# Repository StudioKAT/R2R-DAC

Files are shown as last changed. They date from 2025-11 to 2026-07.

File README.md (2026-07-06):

# R2R DAC
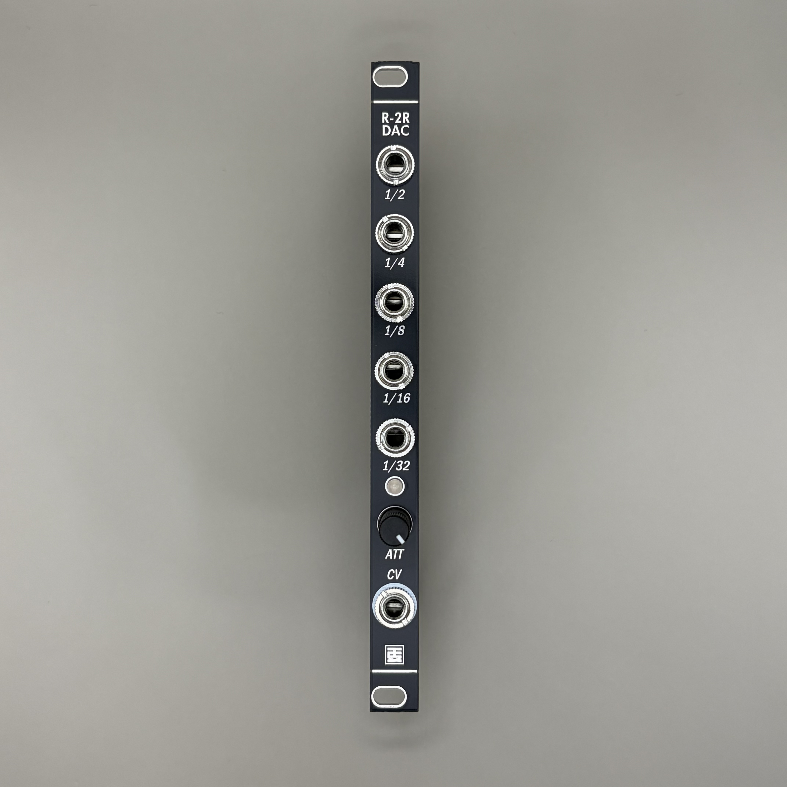
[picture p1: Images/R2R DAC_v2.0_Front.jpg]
R2R DAC_v2.0_Front


## 概要 / Overview

**R2R DAC** は、5つのゲート信号を階段状のコントロール電圧（CV）に変換する、2HPサイズのR-2RラダーDACモジュールです。
5つのゲート入力（/2, /4, /8, /16, /32）のON/OFFの組み合わせによって、0〜31段階のステップ電圧を生成する5ビットのデジタル→アナログ変換器として動作します。

クロックディバイダーやゲートシーケンサーと組み合わせることで、周期的な階段波、疑似ランダムなCVパターン、アルペジオ風のピッチ変化、フィルターやVCAのステップモジュレーションなどを簡単に作ることができます。
CV出力にはアッテネーターを備えており、ピッチCVからモジュレーション用途まで、パッチに合わせて出力レベルを調整できます。

**Update:** v2.0では、v1.0の4ビット仕様から5ビット仕様へ変更され、生成できるステップ数が16段階から32段階に拡張されました。

**R2R DAC** is a compact 2HP R-2R ladder DAC module that converts five gate signals into stepped control voltages (CV).
By combining the ON/OFF states of the five gate inputs (/2, /4, /8, /16, /32), it functions as a 5-bit digital-to-analog converter capable of generating 32 discrete voltage steps (0–31).

When paired with clock dividers or gate sequencers, it can create stepped waveforms, pseudo-random CV patterns, arpeggio-like pitch movement, or stepped modulation for filters, VCAs, and other CV destinations.
The CV output is equipped with an attenuator, allowing the output level to be adjusted for anything from pitch control to general modulation use.

**Update:** In v2.0, the design has been updated from the 4-bit configuration of v1.0 to a 5-bit R-2R DAC, expanding the available resolution from 16 steps to 32 steps.

## 仕様 / Spec
- Format: Eurorack
- Function: R2R DAC
- Current needs: +12V: 15mA, -12V: 15mA
- Width: 2 HP
- Depth: 28mm (including power connector)

## 販売 / Sales

StudioKATオフィシャルショップで販売しています。(日本国内限定)  
https://www.studiokat.jp/items/149564763

## ライセンス / License

この作品は [Creative Commons 表示 - 継承 4.0 国際 (CC BY-SA 4.0)](https://creativecommons.org/licenses/by-sa/4.0/deed.ja) の下でライセンスされています。  
This work is licensed under the [Creative Commons Attribution-ShareAlike 4.0 International License](https://creativecommons.org/licenses/by-sa/4.0/).

## クレジット / Credits

- Designed by : StudioKAT
- Website : https://www.studiokat.jp/
- GitHub : https://github.com/StudioKAT
- X(Twitter) : https://x.com/StudioKAT_synth
- Instagram : https://www.instagram.com/studiokat_modular/

## 更新履歴 / Changelog

- `2025-11-22` v1.0 Released version 1.0
- `2026-07-05` v2.0 Released version 2.0

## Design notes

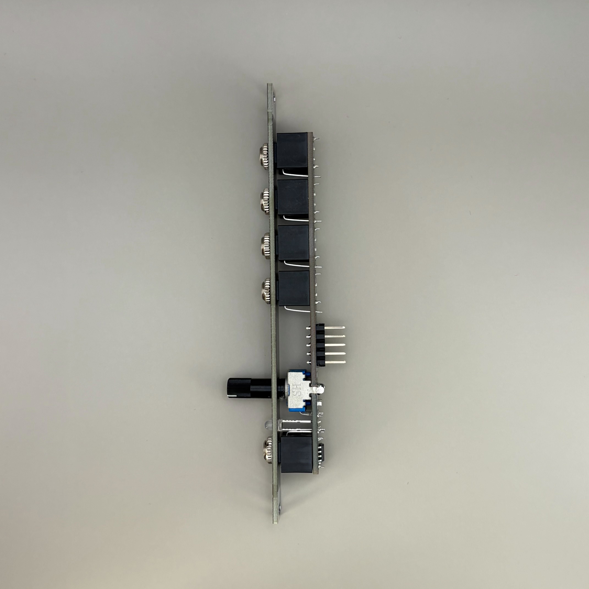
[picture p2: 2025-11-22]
Images/R2R DAC_v1.0_Side.jpg

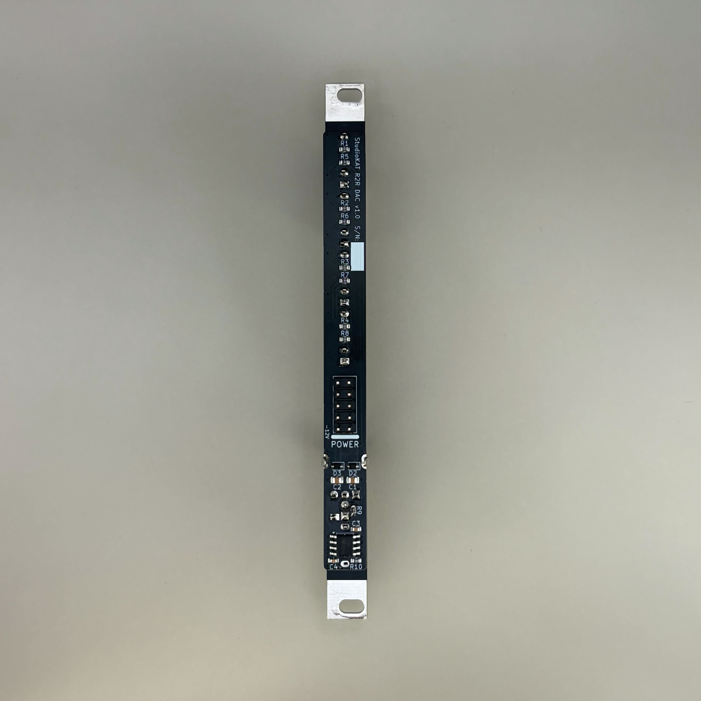
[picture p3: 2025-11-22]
Images/R2R DAC_v1.0_Back.jpg

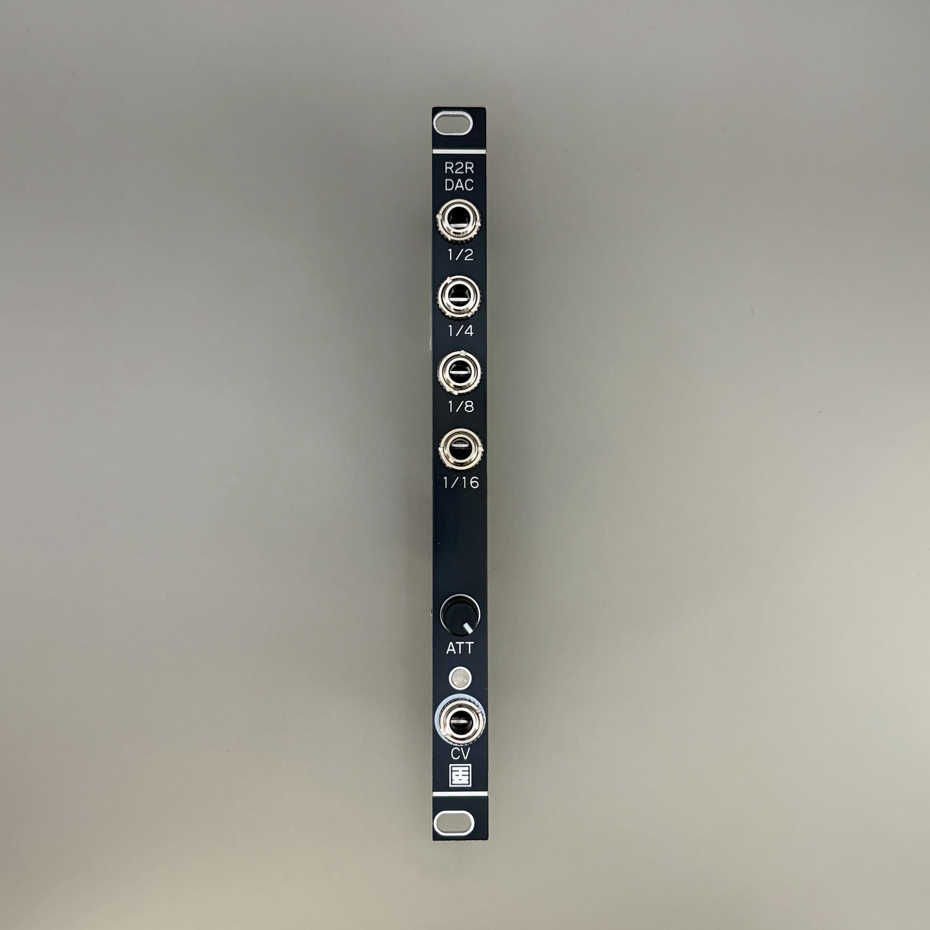
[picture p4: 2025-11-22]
Images/R2R DAC_v1.0_Front.jpg

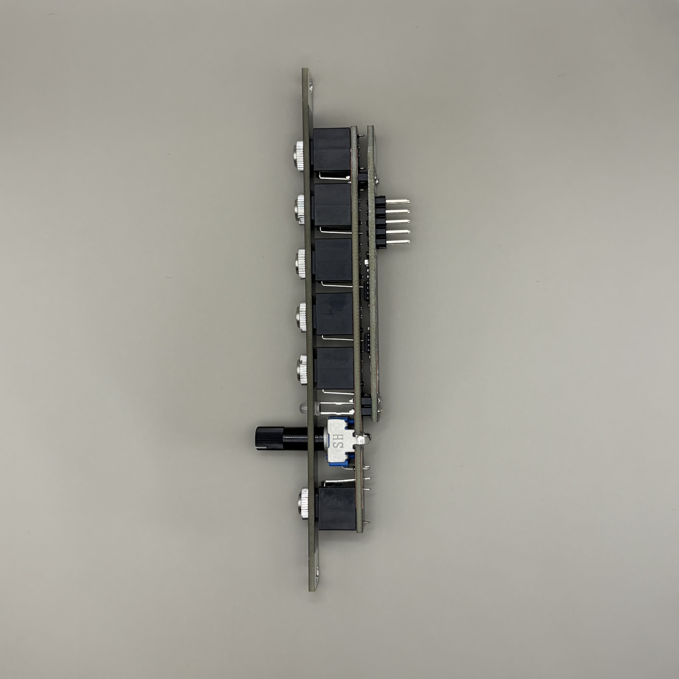
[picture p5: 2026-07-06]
Images/R2R DAC_v2.0_Side.jpg

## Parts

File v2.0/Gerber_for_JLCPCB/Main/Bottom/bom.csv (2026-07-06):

Designator | Footprint | Quantity | Value | LCSC Part #
C1, C2 | 0805 | 2 | 22uF | C45783
C3, C4, C5, C6, C7, C8 | 0603 | 6 | 100nF | C14663
D1, D2 | D_SOD-323 | 2 | 1N5819WS | C64886
J1 | PinHeader_2x05_2.54mm_Europower | 1 | POWER
J12, J13 | PinSocket_1x01_P2.54mm_Vertical | 2 | Conn_01x01_Socket
J14, J15 | PinSocket_1x02_P2.54mm_Vertical | 2 | Conn_01x02_Socket
R11, R12 | 0603 | 2 | 100K | C25803
R13 | 0603 | 1 | 1K | C21190
R14 | 0603 | 1 | 4.7K | C23162
U1, U2 | SOIC-8_3.9x4.9mm_P1.27mm | 2 | TL072CDT | C6961

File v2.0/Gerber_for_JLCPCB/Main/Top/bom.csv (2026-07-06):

Designator | Footprint | Quantity | Value | LCSC Part #
D3 | LED_D3.0mm_Clear | 1 | LED_Dual_Bidirectional
J10, J11 | PinHeader_1x02_P2.54mm_Vertical | 2 | Conn_01x02_Pin
J2 | AudioJack_PJ301M-12 | 1 | IN_1/2
J3 | AudioJack_PJ301M-12 | 1 | IN_1/4
J4 | AudioJack_PJ301M-12 | 1 | IN_1/8
J5 | AudioJack_PJ301M-12 | 1 | IN_1/16
J6 | AudioJack_PJ301M-12 | 1 | IN_1/32
J7 | AudioJack_PJ301M-12 | 1 | CV OUT
J8, J9 | PinHeader_1x01_P2.54mm_Vertical | 2 | Conn_01x01_Pin
R1, R10, R2, R3, R4, R5 | 0603 | 6 | 30K | C22984
R6, R7, R8, R9 | 0603 | 4 | 15K | C22809
RV1 | Potentiometer_RV09 | 1 | B100K

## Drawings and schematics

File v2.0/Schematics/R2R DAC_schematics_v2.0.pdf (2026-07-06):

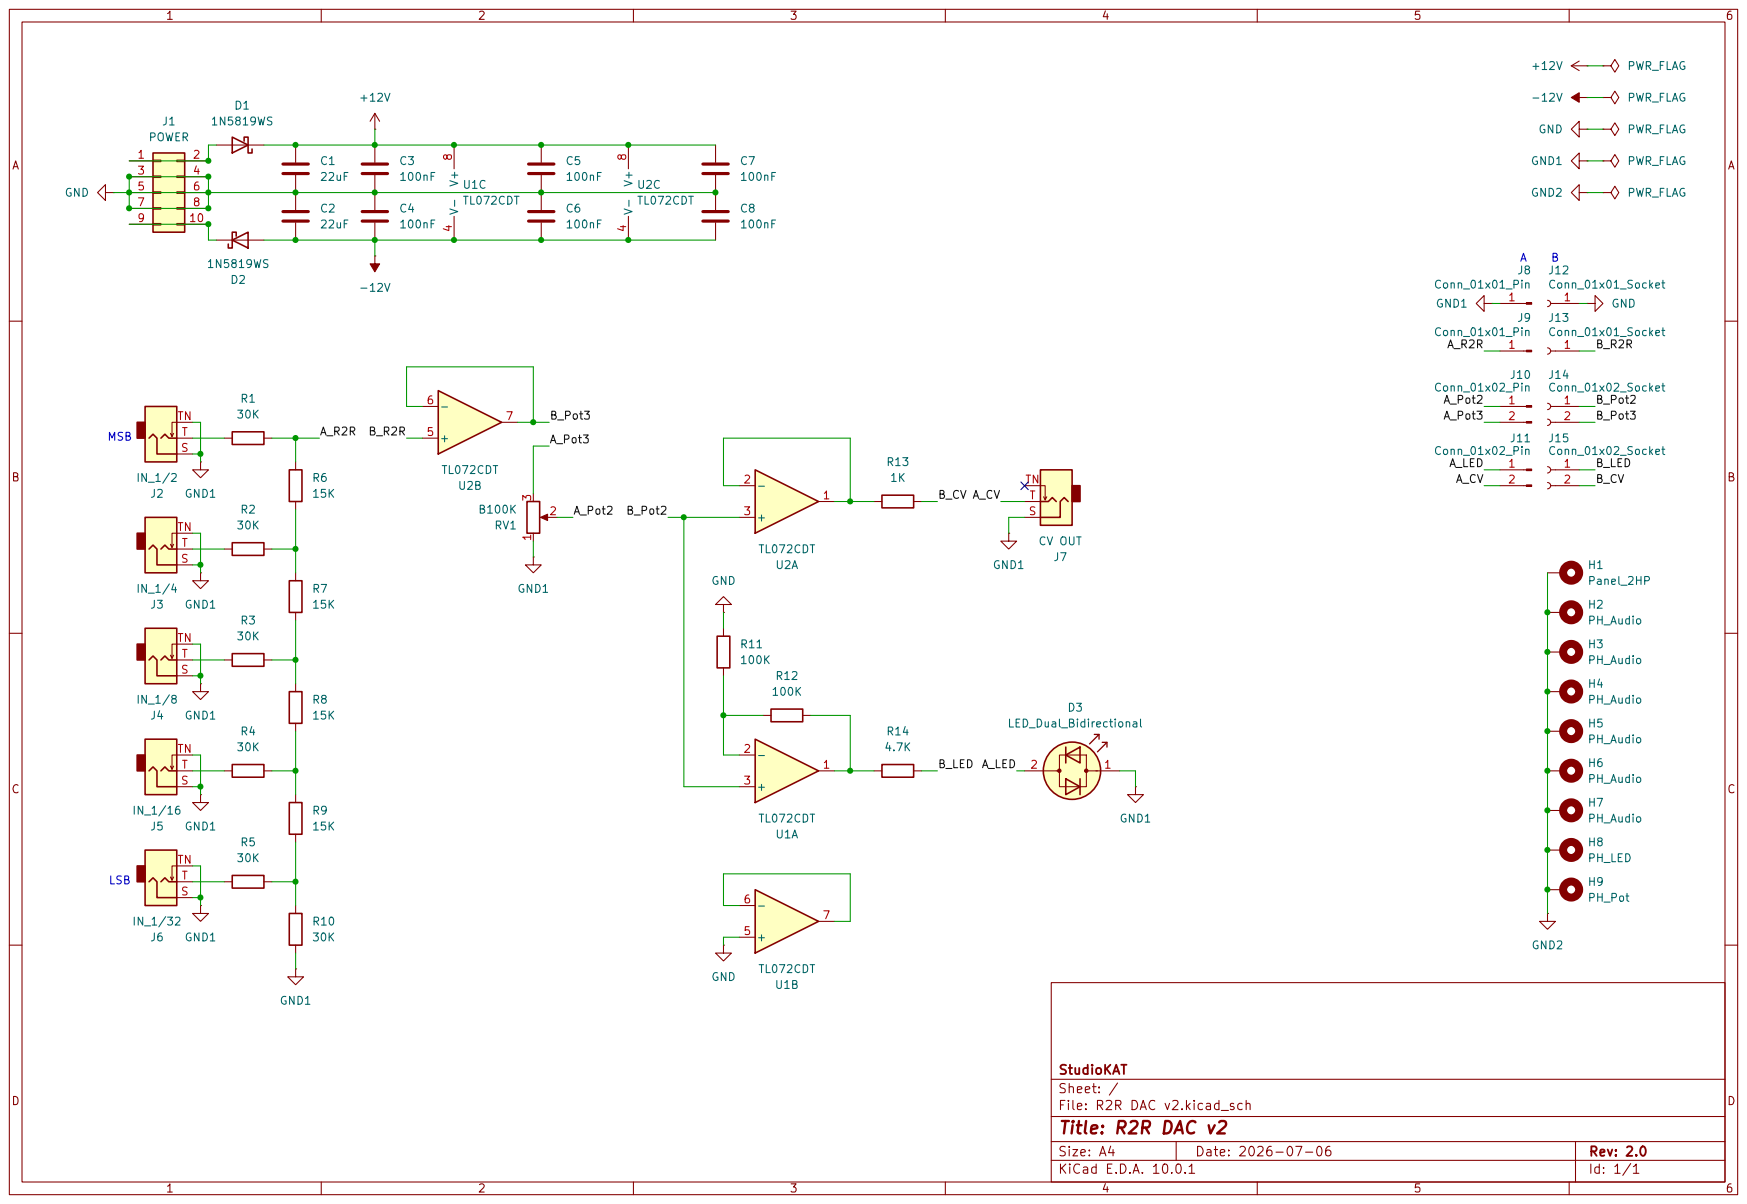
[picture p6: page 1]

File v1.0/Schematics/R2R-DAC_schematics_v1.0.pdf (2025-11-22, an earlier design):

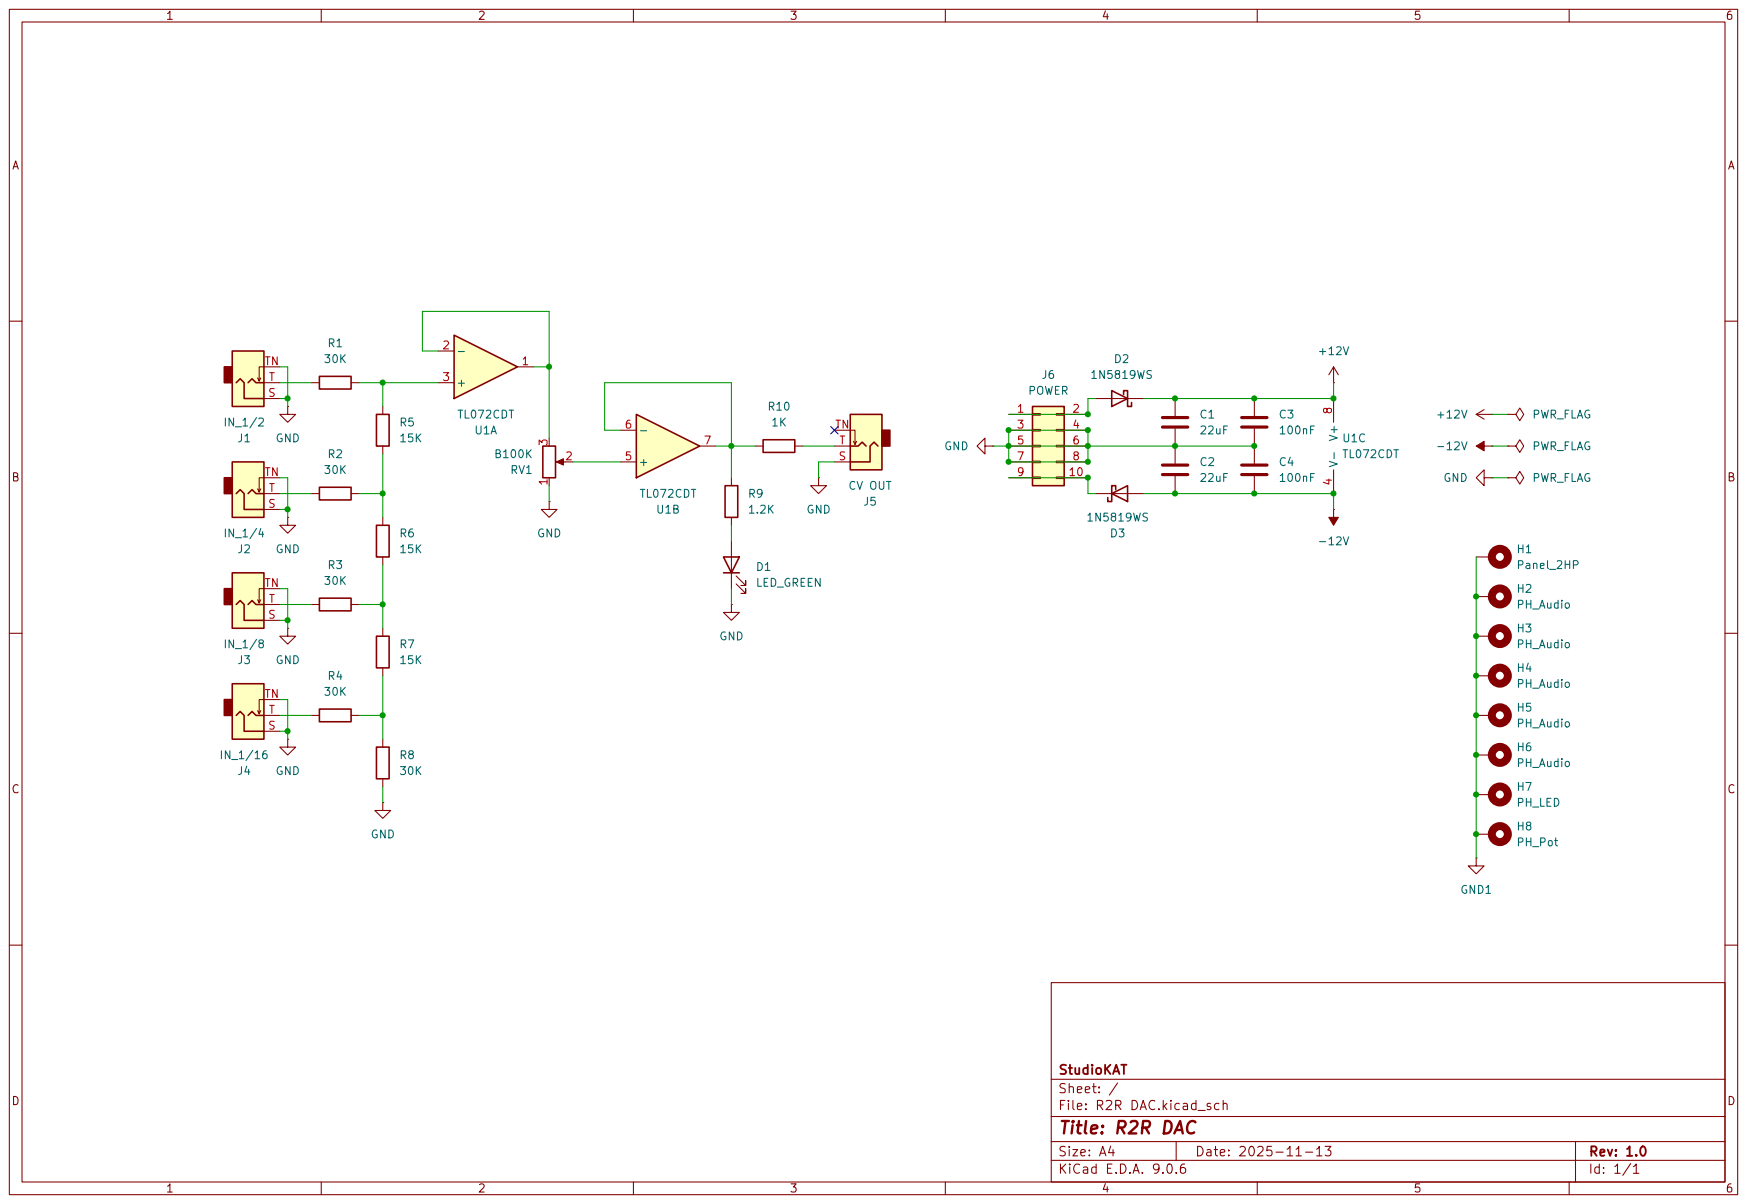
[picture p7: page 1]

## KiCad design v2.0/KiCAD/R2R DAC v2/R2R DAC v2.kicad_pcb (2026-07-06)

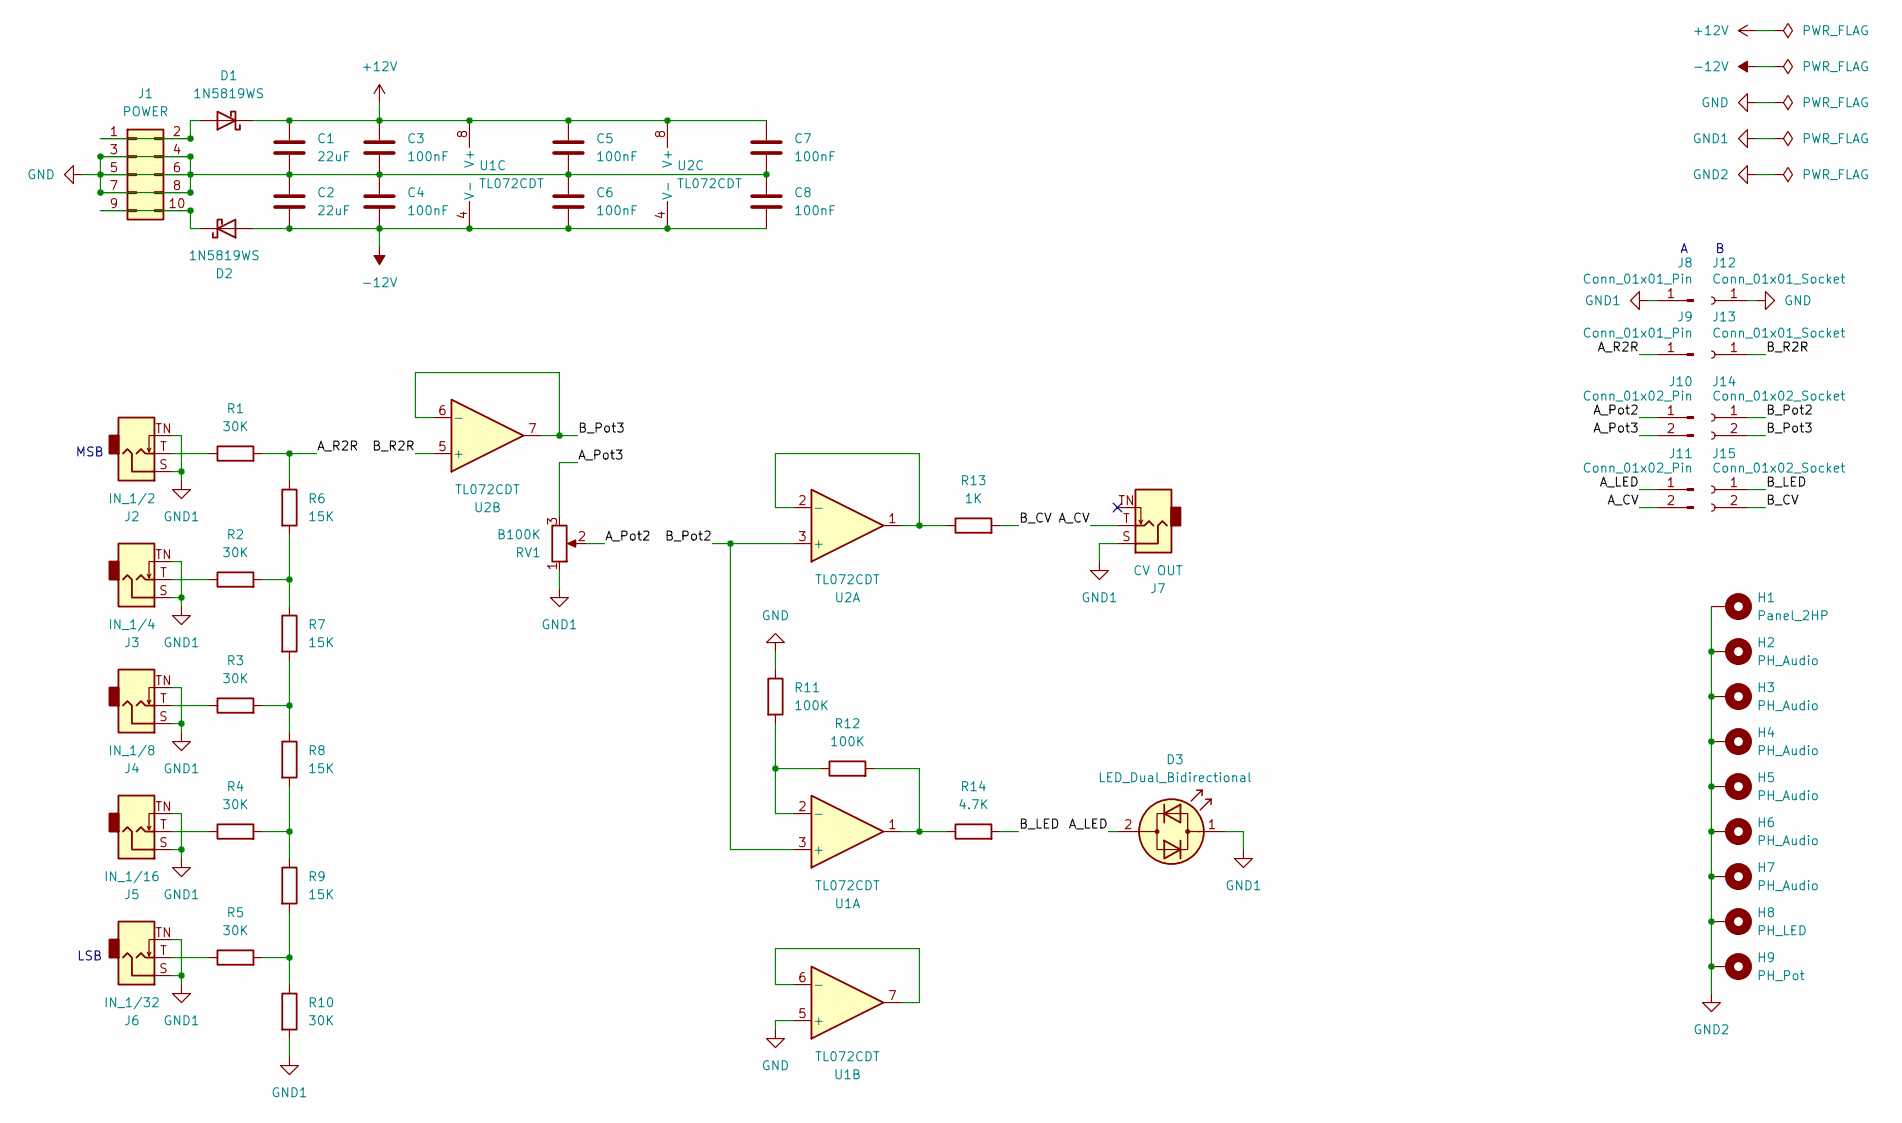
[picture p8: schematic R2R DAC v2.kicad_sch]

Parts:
C1, C2: 22uF; C_0805_2012Metric; LCSC C45783
C3, C4, C5, C6, C7, C8: 100nF; C_0603_1608Metric; LCSC C14663
D1, D2: 1N5819WS; D_SOD-323; LCSC C64886
D3: LED_Dual_Bidirectional; LED_D3.0mm_Clear
H1: Panel_2HP
H2, H3, H4, H5, H6, H7: PH_Audio; PH_AudioJack_3.5mm_Pad
H8: PH_LED; PH_LED_3.0mm_Pad
H9: PH_Pot; PH_RV09
J1: POWER; PinHeader_2x05_2.54mm_Europower
J2: IN_1/2; AudioJack_PJ301M-12
J3: IN_1/4; AudioJack_PJ301M-12
J4: IN_1/8; AudioJack_PJ301M-12
J5: IN_1/16; AudioJack_PJ301M-12
J6: IN_1/32; AudioJack_PJ301M-12
J7: CV OUT; AudioJack_PJ301M-12
J8, J9: Conn_01x01_Pin; PinHeader_1x01_P2.54mm_Vertical
J10, J11: Conn_01x02_Pin; PinHeader_1x02_P2.54mm_Vertical
J12, J13: Conn_01x01_Socket; PinSocket_1x01_P2.54mm_Vertical
J14, J15: Conn_01x02_Socket; PinSocket_1x02_P2.54mm_Vertical
R1, R2, R3, R4, R5, R10: 30K; R_0603_1608Metric; LCSC C22984
R6, R7, R8, R9: 15K; R_0603_1608Metric; LCSC C22809
R11, R12: 100K; R_0603_1608Metric; LCSC C25803
R13: 1K; R_0603_1608Metric; LCSC C21190
R14: 4.7K; R_0603_1608Metric; LCSC C23162
RV1: B100K; Potentiometer_RV09
U1, U2: TL072CDT; SOIC-8_3.9x4.9mm_P1.27mm; LCSC C6961

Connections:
+12V: C1.1, C3.1, C5.1, C7.1, D1.1 (K), U1.8 (V+), U2.8 (V+)
-12V: C2.2, C4.2, C6.2, C8.2, D2.2 (A), U1.4 (V-), U2.4 (V-)
/A_CV: J7.T, J11.2
/A_LED: D3.2 (AK), J11.1
/A_Pot2: J10.1, RV1.2
/A_Pot3: J10.2, RV1.3
/A_R2R: J9.1 (Pin_1_1), R1.2, R6.1
/B_CV: J15.2, R13.2
/B_LED: J15.1, R14.2
/B_Pot2: J14.1, U1.3 (+), U2.3 (+)
/B_Pot3: J14.2, U2.6 (-), U2.7
/B_R2R: J13.1 (Pin_1_1), U2.5 (+)
GND: C1.2, C2.1, C3.2, C4.1, C5.2, C6.1, C7.2, C8.1, J1.3, J1.4, J1.5, J1.6, J1.7, J1.8, J12.1 (Pin_1_1), R11.1, U1.5 (+)
GND1: D3.1 (KA), J2.S, J2.TN, J3.S, J3.TN, J4.S, J4.TN, J5.S, J5.TN, J6.S, J6.TN, J7.S, J8.1 (Pin_1_1), R10.2, RV1.1
GND2: H1.1 (1_1), H2.1 (1_1), H3.1 (1_1), H4.1 (1_1), H5.1 (1_1), H6.1 (1_1), H7.1 (1_1), H8.1 (1_1), H9.1 (1_1)
unnamed: D1.2 (A), J1.1, J1.2
unnamed: D2.1 (K), J1.9, J1.10
unnamed: J2.T, R1.1
unnamed: J3.T, R2.1
unnamed: J4.T, R3.1
unnamed: J5.T, R4.1
unnamed: J6.T, R5.1
unnamed: R2.2, R6.2, R7.1
unnamed: R3.2, R7.2, R8.1
unnamed: R4.2, R8.2, R9.1
unnamed: R5.2, R9.2, R10.1
unnamed: R12.2, R14.1, U1.1
unnamed: R11.2, R12.1, U1.2 (-)
unnamed: U1.6 (-), U1.7
unnamed: R13.1, U2.1, U2.2 (-)

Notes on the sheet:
MSB
A B
LSB

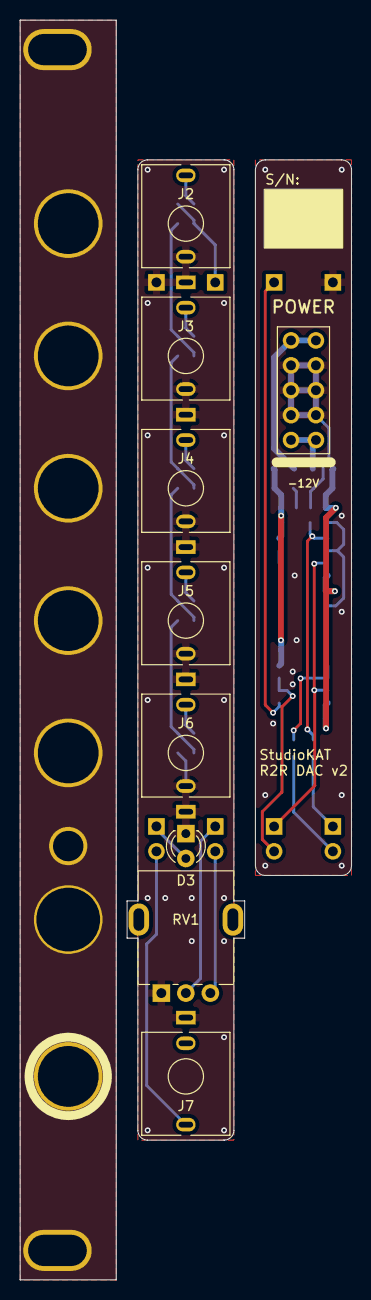
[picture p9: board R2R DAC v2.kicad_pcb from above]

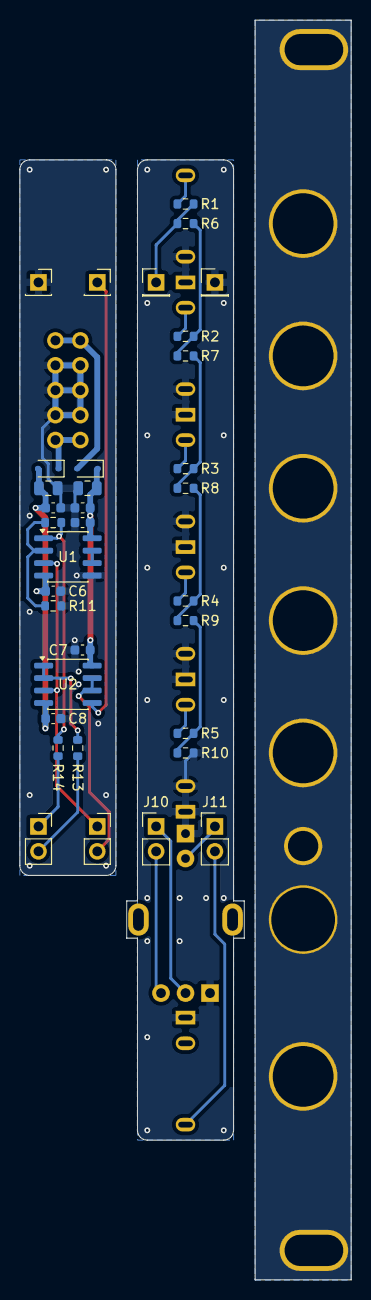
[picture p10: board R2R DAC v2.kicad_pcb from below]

Board: 2 copper layers, 33.8 x 128.5 mm, 52 parts (34 on the bottom side), 30 nets.

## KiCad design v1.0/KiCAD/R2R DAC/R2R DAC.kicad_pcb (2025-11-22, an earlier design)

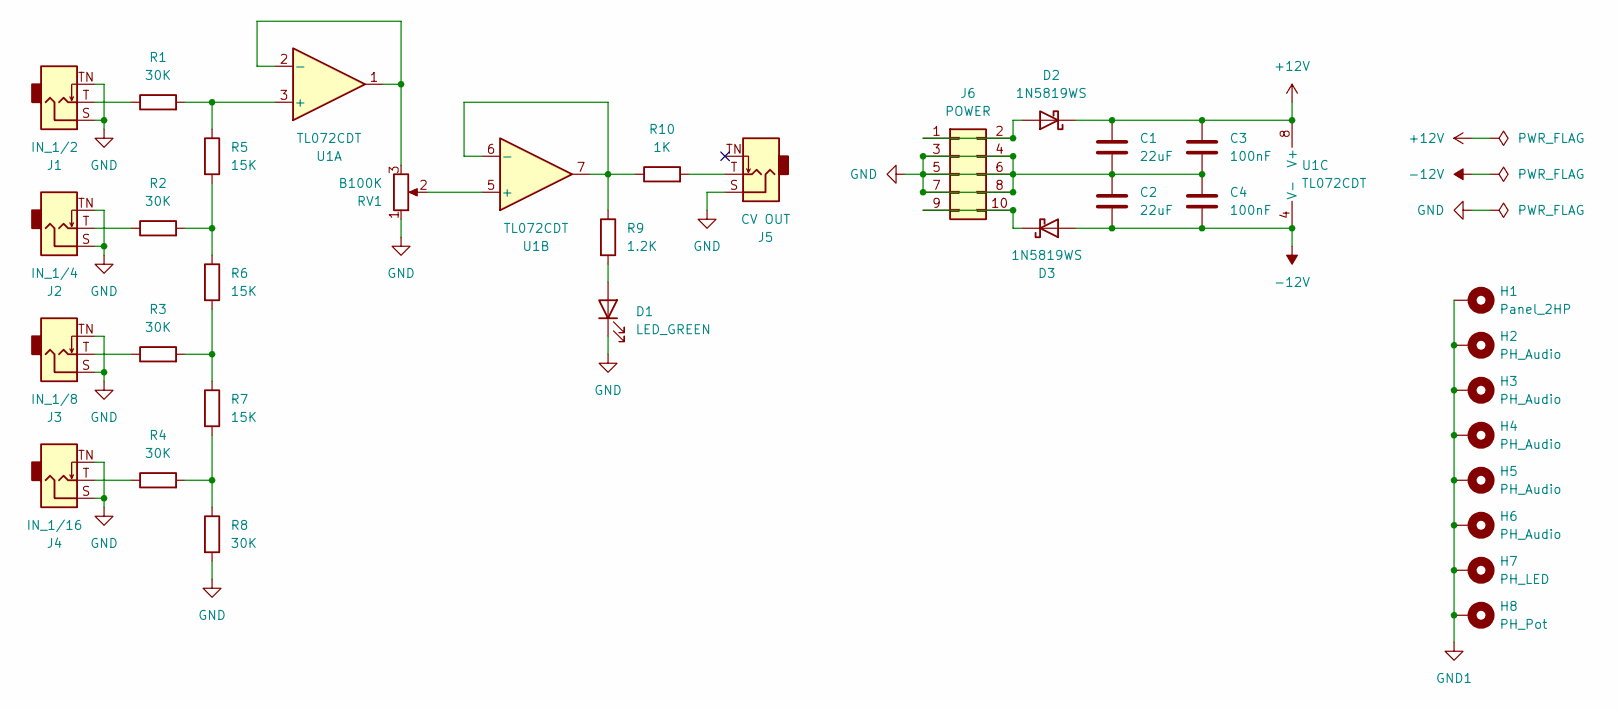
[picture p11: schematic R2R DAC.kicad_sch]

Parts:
C1, C2: 22uF; C_0805_2012Metric; LCSC C45783
C3, C4: 100nF; C_0603_1608Metric; LCSC C14663
D1: LED_GREEN; LED_D3.0mm_2hp
D2, D3: 1N5819WS; D_SOD-323; LCSC C64886
H1: Panel_2HP
H2, H3, H4, H5, H6: PH_Audio; PH_AudioJack_3.5mm_Pad
H7: PH_LED; PH_LED_3.0mm_Pad
H8: PH_Pot; PH_RV09
J1: IN_1/2; AudioJack_PJ301M-12
J2: IN_1/4; AudioJack_PJ301M-12
J3: IN_1/8; AudioJack_PJ301M-12
J4: IN_1/16; AudioJack_PJ301M-12
J5: CV OUT; AudioJack_PJ301M-12_2hp_R
J6: POWER; PinHeader_2x05_2.54mm_Europower
R1, R2, R3, R4, R8: 30K; R_0603_1608Metric; LCSC C22984
R5, R6, R7: 15K; R_0603_1608Metric; LCSC C22809
R9: 1.2K; R_0603_1608Metric; LCSC C22765
R10: 1K; R_0603_1608Metric; LCSC C21190
RV1: B100K; Potentiometer_RV09
U1: TL072CDT; SOIC-8_3.9x4.9mm_P1.27mm; LCSC C6961

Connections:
+12V: C1.1, C3.1, D2.1 (K), U1.8 (V+)
-12V: C2.2, C4.2, D3.2 (A), U1.4 (V-)
GND: C1.2, C2.1, C3.2, C4.1, D1.1 (K), J1.S, J1.TN, J2.S, J2.TN, J3.S, J3.TN, J4.S, J4.TN, J5.S, J6.3, J6.4, J6.5, J6.6, J6.7, J6.8, R8.2, RV1.1
GND1: H1.1, H2.1, H3.1, H4.1, H5.1, H6.1, H7.1, H8.1
unnamed: D1.2 (A), R9.2
unnamed: D2.2 (A), J6.1, J6.2
unnamed: D3.1 (K), J6.9, J6.10
unnamed: J1.T, R1.1
unnamed: J2.T, R2.1
unnamed: J3.T, R3.1
unnamed: J4.T, R4.1
unnamed: J5.T, R10.2
unnamed: R2.2, R5.2, R6.1
unnamed: R3.2, R6.2, R7.1
unnamed: R4.2, R7.2, R8.1
unnamed: R1.2, R5.1, U1.3 (+)
unnamed: RV1.3, U1.1, U1.2 (-)
unnamed: RV1.2, U1.5 (+)
unnamed: R9.1, R10.1, U1.6 (-), U1.7

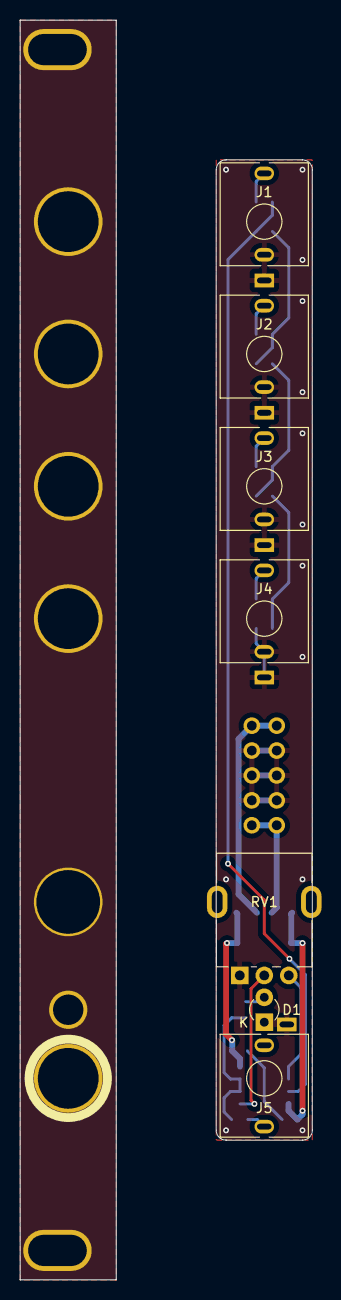
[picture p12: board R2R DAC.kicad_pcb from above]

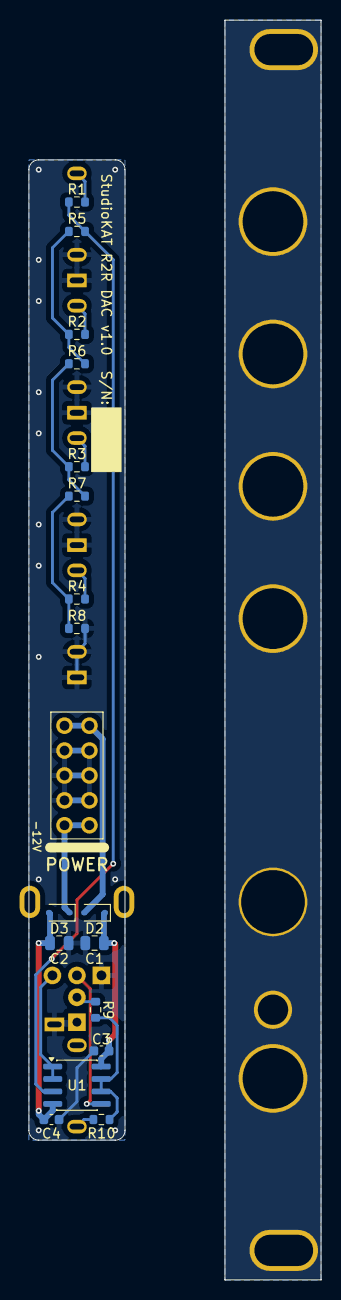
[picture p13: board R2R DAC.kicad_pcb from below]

Board: 2 copper layers, 29.8 x 128.5 mm, 33 parts (18 on the bottom side), 19 nets.

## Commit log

2026-07-06 v2.0追加
    [R2R DAC v2.kicad_pcb, R2R DAC v2.kicad_sch, bom.csv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]
2026-07-06 消費電力を実測値に変更
